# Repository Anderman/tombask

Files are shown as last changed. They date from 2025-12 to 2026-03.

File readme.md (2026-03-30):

Tosot (Gree) Hombask 200Liter

The signal is custom rs485
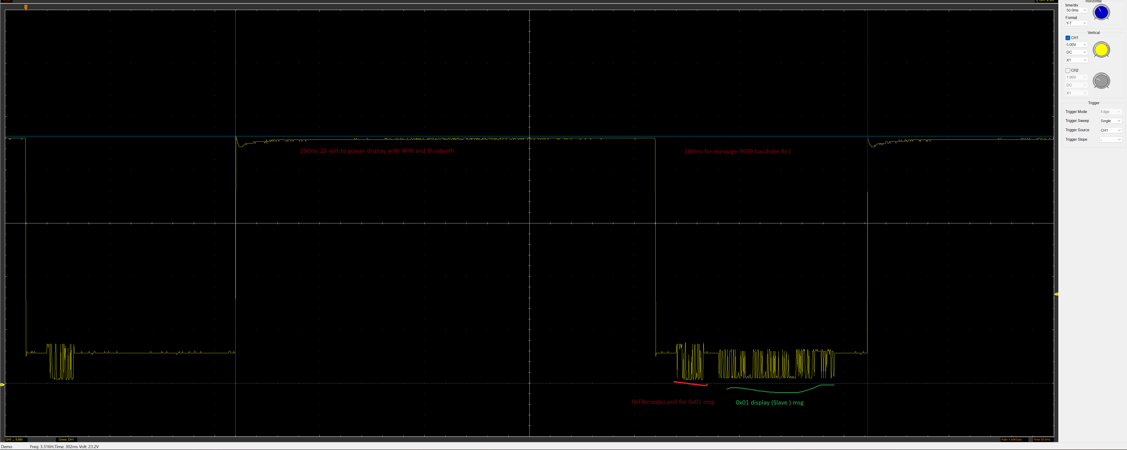
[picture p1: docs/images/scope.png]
RS485 scope capture


All message send
```
12-07 12:47:05 frame=7e 7e 00 f0 00 04 90 31 01 64 47 00 (poll slave 0x00)
12-07 12:47:06 frame=7e 7e 01 f0 00 04 90 31 01 74 87 00 (poll slave 0x01)
12-07 12:47:06 frame=7e 7e f0 01 02 2d 90 31 01 15 21 9a 40 4a 02 c0 02 05 01 c7 01 0c 02 0e 02 c4 00 24 01 17 b4 00 00 00 00 55 8e 5d a7 15 b0 8e 00 aa ff ff ff ff ff 73 4a 57 55 (response slave 0x01)
12-07 12:47:06 frame=7e 7e 02 f0 00 04 90 31 01 47 87 00 (poll slave 0x02)
12-07 12:47:06 frame=7e 7e f0 f0 04 2d 90 31 01 15 21 9a 40 4a 02 c0 02 05 01 c7 01 0c 02 0e 02 c4 00 24 01 17 b4 00 00 00 00 55 8e 5d a7 15 b0 8e 00 aa ff ff ff ff ff 73 73 f6 00 (broadcast master)
12-07 12:47:06 frame=7e 7e f0 f0 06 1c 90 31 01 15 2c c0 01 00 00 10 ff ff 00 00 af b4 04 4b 73 5f 5a 3a 4b 00 00 00 00 99 1f 00 (broadcast master)
12-07 12:47:07 frame=7e 7e f0 f0 02 3c 90 31 01 77 98 00 7d 00 00 00 00 76 00 74 75 00 00 10 01 01 90 00 00 00 00 f8 00 00 00 00 00 00 00 11 8c 0f 9f c6 1d 98 15 00 00 00 00 70 9a 00 00 00 00 02 00 00 00 00 02 00 00 5a f0 00 (broadcast master)
12-07 12:47:07 frame=7e 7e f0 f0 03 25 90 31 06 00 00 00 14 14 00 00 00 00 00 00 00 00 00 00 00 00 00 00 00 02 00 00 00 00 00 00 00 00 00 00 00 09 98 44 00 (broadcast master)
12-07 12:47:07 frame=7e 7e f0 f0 08 40 90 31 01 01 00 00 00 00 00 00 00 00 00 00 00 00 00 00 00 00 00 00 00 00 00 00 00 00 00 00 00 00 00 00 00 00 00 00 00 00 00 00 00 00 00 00 00 00 00 00 00 00 00 00 00 00 00 00 00 00 00 00 00 ae 60 00 (broadcast master)
```
Slave can send after a poll frame.
Slave is ready sending when the last padding byte is 0x55
To write byte 0x08 must be 0x02

Aansluiting Rs485 signal for wired controller on H1(pos) and H2(neg) of the XT3 connector
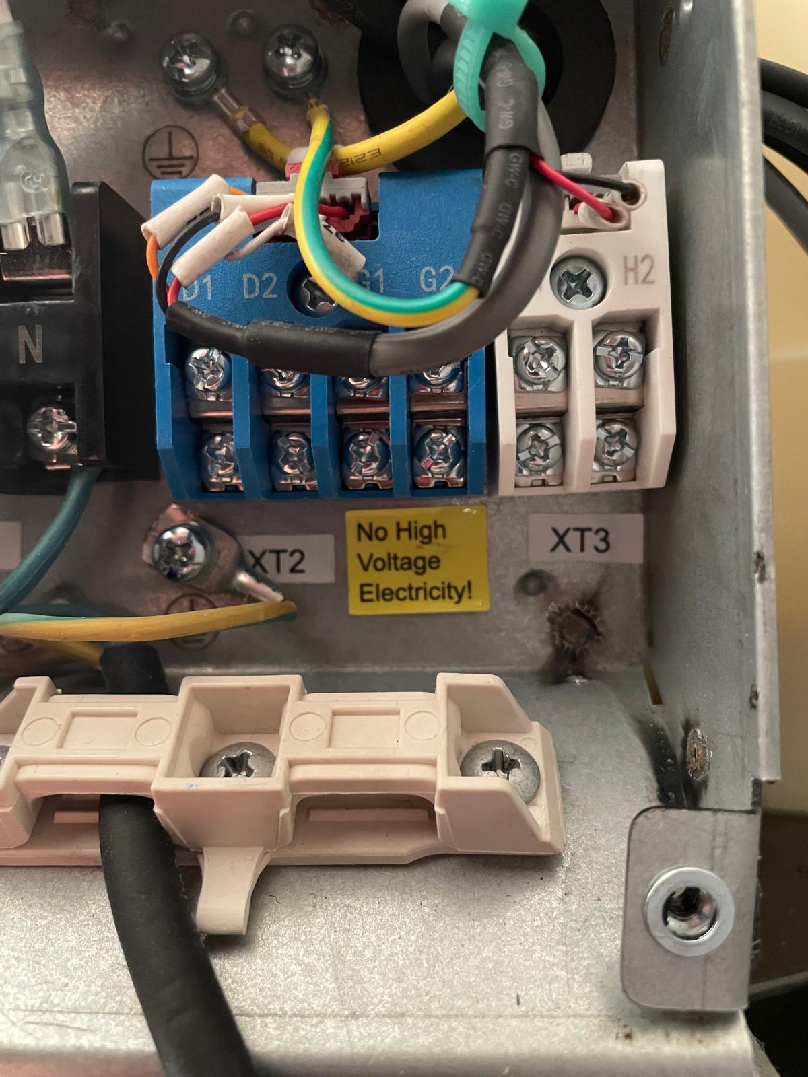
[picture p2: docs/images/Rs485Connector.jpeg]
RS485 connector


App 
## Control page

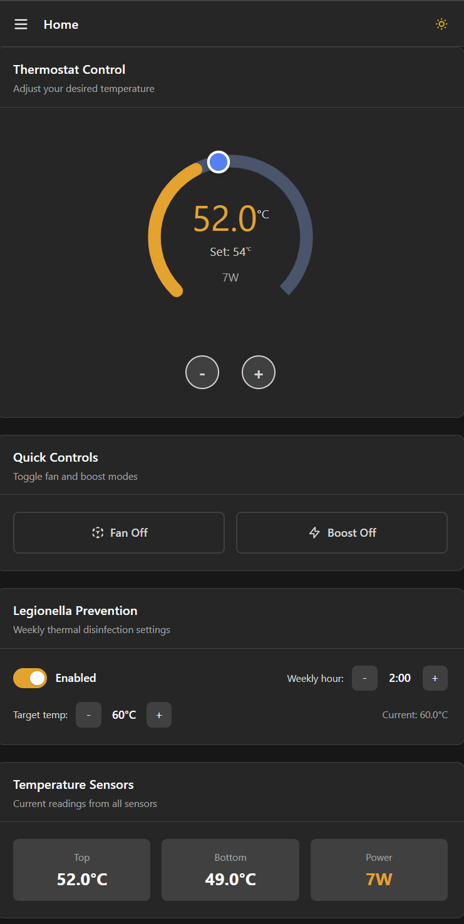
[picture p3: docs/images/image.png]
Control page


## temp history
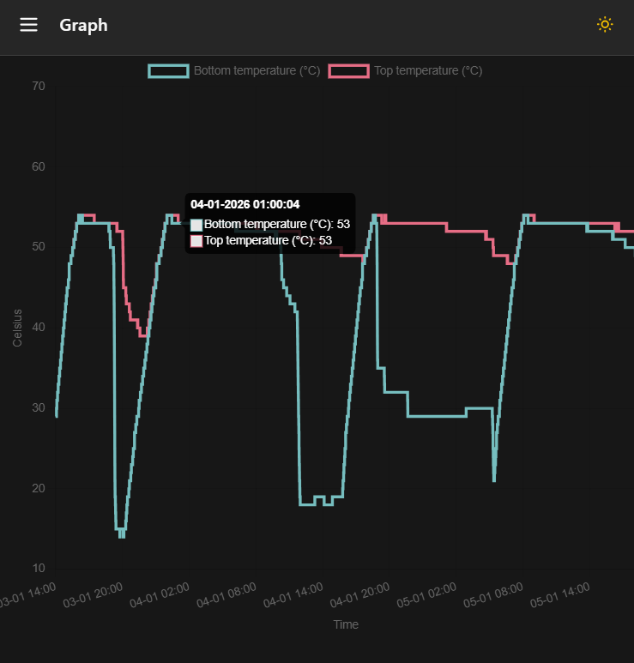
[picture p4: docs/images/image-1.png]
Temperature history


## mtqq settings
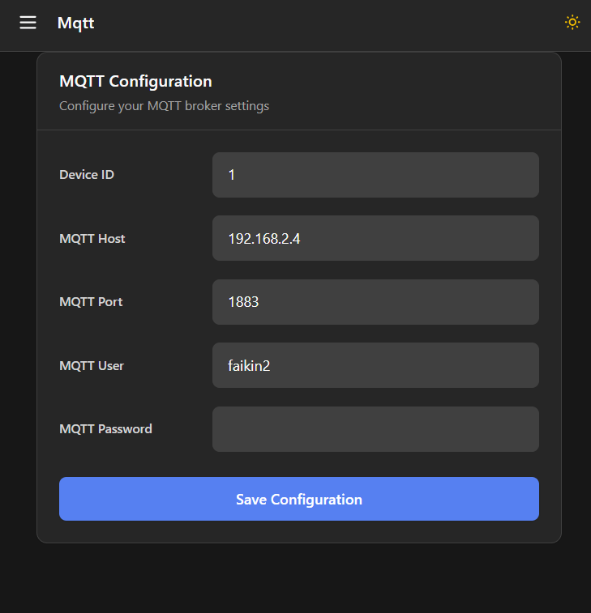
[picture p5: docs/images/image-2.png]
MQTT settings


## Logger (for debugging)
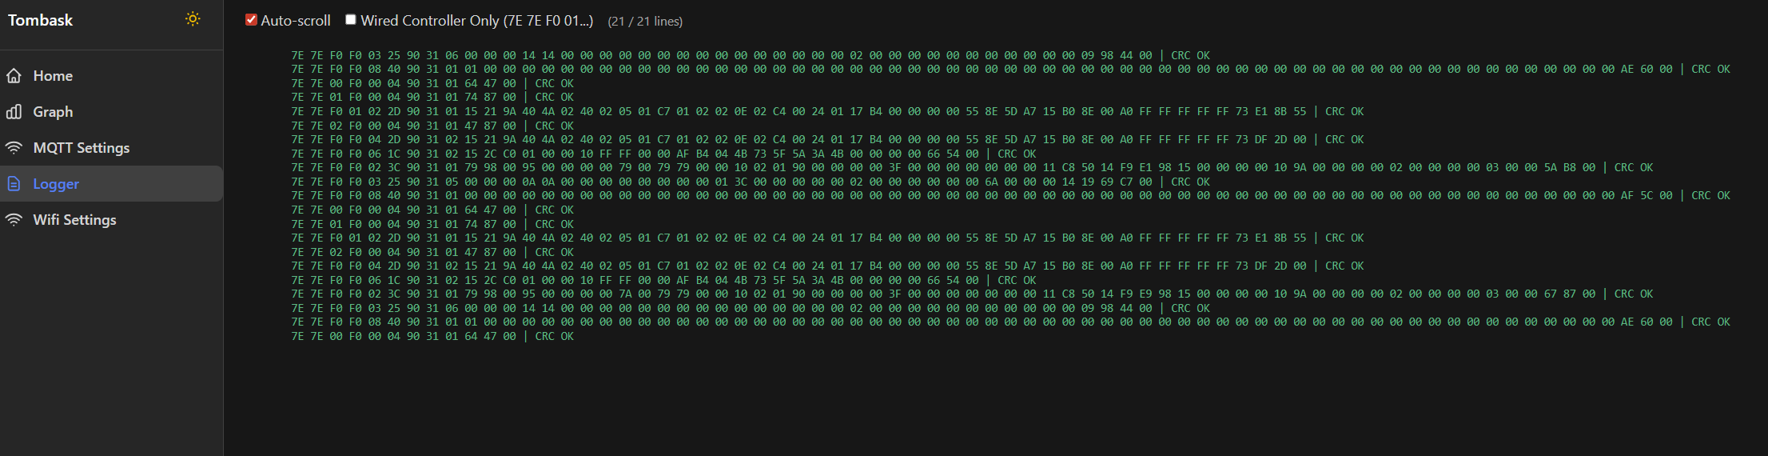
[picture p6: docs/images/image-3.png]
Logger


## wifi settings
This is the wifimanger plugin

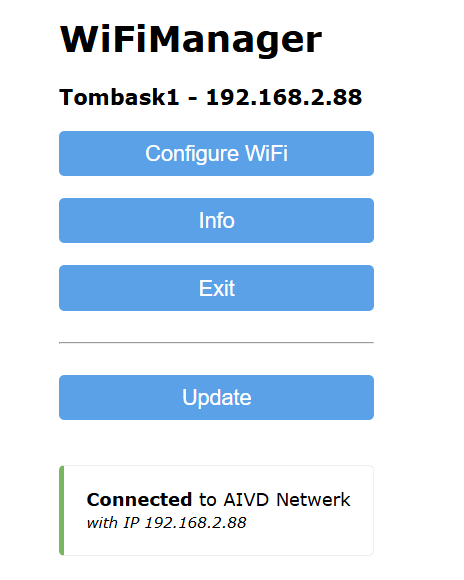
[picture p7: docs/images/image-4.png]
WiFi settings


PCB
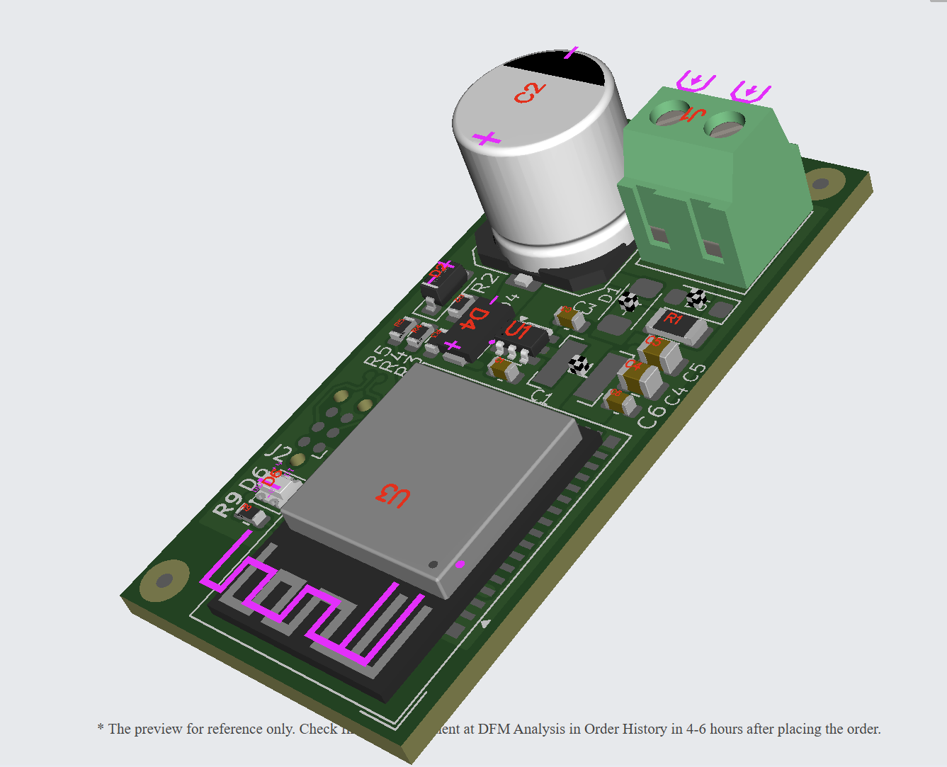
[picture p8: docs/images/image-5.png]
PCB


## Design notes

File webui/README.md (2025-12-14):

# Tombask Web UI

Minimal Svelte (Vite) web UI to edit device config on the ESP32.

## Dev

From `webui/`:
- `pnpm install`
- `pnpm run dev`

## Build

- `pnpm run build`

Output goes to `webui/dist/` with stable filenames:
- `dist/index.html`
- `dist/assets/app.js`
- `dist/assets/app.css`

## Expected device API

- `GET /api/config` -> JSON:
  ```json
  {
    "deviceId": "tombask-kitchen",
    "mqttHost": "192.168.2.4",
    "mqttPort": 1883,
    "wifiSsid": "MyWiFi",
    "wifiPassword": ""
  }
  ```
- `POST /api/config` (JSON) -> returns 200 OK (optionally JSON).

Recommended: device does not return the stored wifi password; only updates it when a non-empty value is posted.

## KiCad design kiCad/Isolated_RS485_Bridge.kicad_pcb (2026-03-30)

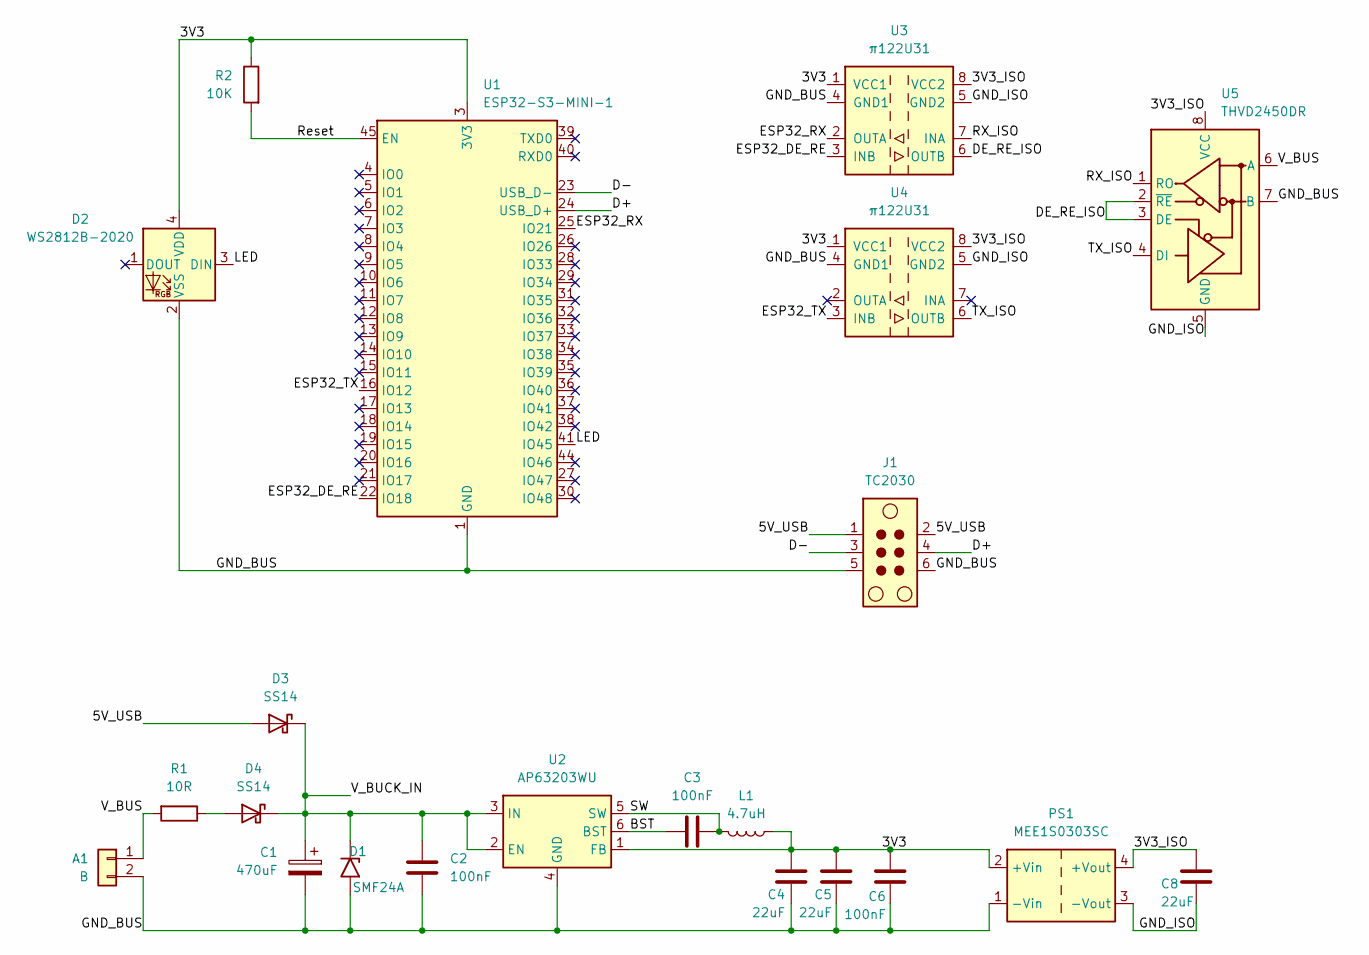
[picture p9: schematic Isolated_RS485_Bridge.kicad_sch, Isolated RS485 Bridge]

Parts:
A1: B; TerminalBlock_Phoenix_MKDS-1-2-3.81_1x02_P3.81mm_Horizontal; LCSC C5188452
C1: 470uF; CP_Elec_10x10; LCSC C3350
C2, C3, C6: 100nF; C_0603_1608Metric; LCSC C56476
C4, C5, C8: 22uF; C_0805_2012Metric; LCSC C45783
D1: SMF24A; D_SOD-123FL; LCSC C545276
D2: WS2812B-2020; LED_WS2812B-2020_2x2.2mm; LCSC C965555
D3, D4: SS14; D_SOD-323HE; LCSC C28646397
J1: TC2030; Tag-Connect_TC2030-IDC-NL_2x03_P1.27mm_Vertical
L1: 4.7uH; L_Bourns-SRN4018; LCSC C5159668
PS1: MEE1S0303SC; Converter_DCDC_Murata_MEE1SxxxxSC_THT; LCSC C7465185
R1: 10R; R_1206_3216Metric; LCSC C17903
R2: 10K; R_0603_1608Metric; LCSC C25804
U1: ESP32-S3-MINI-1; LCSC C3013941
U2: AP63203WU; TSOT-23-6; LCSC C780769
U3, U4: π122U31; SOIC-8_3.9x4.9mm_P1.27mm; LCSC C471590
U5: THVD2450DR; SOIC-8_3.9x4.9mm_P1.27mm; LCSC C2672621

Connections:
/3V3: C4.1, C5.1, C6.2, D2.4 (VDD), L1.1, PS1.2 (+Vin), R2.1, U1.3 (3V3), U2.1 (FB), U3.1 (VCC1), U4.1 (VCC1)
/3V3_ISO: C8.1, PS1.4 (+Vout), U3.8 (VCC2), U4.8 (VCC2), U5.8 (VCC)
/5V_USB: D3.2 (A), J1.1, J1.2
/BST: C3.2, U2.6 (BST)
/D+: J1.4, U1.24 (USB_D+)
/D-: J1.3, U1.23 (USB_D-)
/DE_RE_ISO: U3.6 (OUTB), U5.2 (~RE), U5.3 (DE)
/ESP32_DE_RE: U1.22 (IO18), U3.3 (INB)
/ESP32_RX: U1.25 (IO21), U3.2 (OUTA)
/ESP32_TX: U1.16 (IO12), U4.3 (INB)
/GND_BUS: A1.2, C1.2, C2.2, C4.2, C5.2, C6.1, D1.2 (A2), D2.2 (VSS), J1.5, J1.6, PS1.1 (-Vin), U1.1 (GND), U1.2 (GND), U1.42 (GND), U1.43 (GND), U1.46 (GND), U1.47 (GND), U1.48 (GND), U1.49 (GND), U1.50 (GND), U1.51 (GND), U1.52 (GND), U1.53 (GND), U1.54 (GND), U1.55 (GND), U1.56 (GND), U1.57 (GND), U1.58 (GND), U1.59 (GND), U1.60 (GND), U1.61 (GND), U1.62 (GND), U1.63 (GND), U1.64 (GND), U1.65 (GND), U2.4 (GND), U3.4 (GND1), U4.4 (GND1), U5.7 (B)
/GND_ISO: C8.2, PS1.3 (-Vout), U3.5 (GND2), U4.5 (GND2), U5.5 (GND)
/LED: D2.3 (DIN), U1.41 (IO45)
/RX_ISO: U3.7 (INA), U5.1 (RO)
/Reset: R2.2, U1.45 (EN)
/SW: C3.1, L1.2, U2.5 (SW)
/TX_ISO: U4.6 (OUTB), U5.4 (DI)
/V_BUCK_IN: C1.1, C2.1, D1.1 (A1), D3.1 (K), D4.1 (K), U2.2 (EN), U2.3 (IN)
/V_BUS: A1.1, R1.2, U5.6 (A)
unnamed: D4.2 (A), R1.1

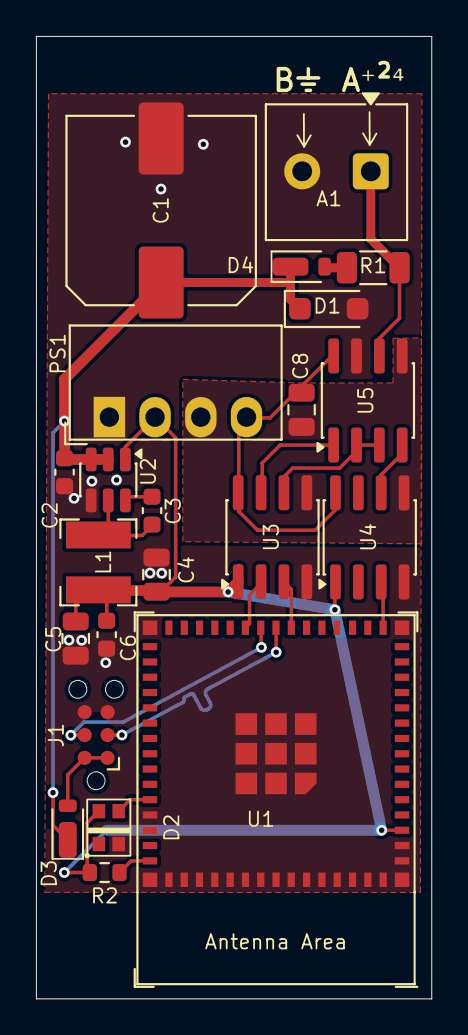
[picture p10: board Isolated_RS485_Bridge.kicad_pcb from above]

Board: 2 copper layers, 22.0 x 53.5 mm, 22 parts (0 on the bottom side), 20 nets.

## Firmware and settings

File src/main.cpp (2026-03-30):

#include <Arduino.h>
#include <WiFi.h>
#include <PubSubClient.h>
#include <ArduinoOTA.h>
#include <cstdio>
#include "secrets.h"
#include "mqtt/setup.h"
#include "mqtt/mqttLoop.h"
#include "Ota.h"
#include "ota/auto_update.h"
#include "wifiSetup.h"
#include "rs485/rs485.h"
#include "storage/storage.h"
#include "storage/sensor_log.h"
#include "webui/webui.h"
#include "rs485/settings.h"
#include "status_led.h"

// ==== GLOBALS ====
WiFiClient espClient;
PubSubClient mqttClient(espClient);
unsigned long lastPublish = 0;

void setup()
{
  Serial.begin(115200);
  delay(2000);
  Serial.println();
  Serial.println("[tombask] boot");

  statusLedSetup();
  // Boot indication (dim blue)
  statusLedSetRgb(0, 0, 16);

  loadConfig();
  listNvsKeys();
  loadAllSensorLogs();
  Serial.print("[tombask] deviceId=");
  Serial.println(deviceId);
  setupWifi();
  Serial.print("setupWifi done, IP=");
  Serial.print(WiFi.localIP());
  Serial.println();
  setupOTA();
  setupWebUi();
  setupAutoUpdate();
  setupWifiConfigPage();
  Serial.print("[tombask] webui started: http://");
  Serial.print(WiFi.localIP());
  Serial.println("/");
  setupMqtt();
  setupRs485();
  Serial.println("[tombask] setup done");

  // Ready indication (dim green)
  statusLedSetRgb(0, 16, 0);
}

void loop()
{
  static unsigned long lastLogSave = 0;
  ArduinoOTA.handle();
  autoUpdateLoop();
  webUiLoop();
  wifiManagerLoop();
  mqttLoop();
  rs485Loop();
  if (millis() - lastLogSave > 1UL * 60 * 1000) { // elke 1 min
    saveAllSensorLogs();
    lastLogSave = millis();
  }
}

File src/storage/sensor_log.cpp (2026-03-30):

#include <FS.h>
#include <ArduinoJson.h>
#include <Preferences.h>
#include "sensor_log.h"
#include <time.h>
#include <set>

// Forward declarations for logs in each frame file
SensorLog topTempLog("TTop");
SensorLog bottomTempLog("TBottom");
static SensorLog *const allLogs[] = {&topTempLog, &bottomTempLog};

SensorLog::SensorLog(const char *name, size_t maxEntries)
    : _maxEntries(maxEntries), name(name) {}

void SensorLog::log(int16_t value)
{
    u_int32_t timestamp = time(nullptr); // epoch seconds
    while (entries.size() >= _maxEntries)
    {
        entries.erase(entries.begin()); // ringbuffer: verwijder oudste
    }
    entries.push_back({timestamp, value});
}

void SensorLog::logIfChanged(int16_t logValue)
{
    const size_t bufferSize = 5;
    _lastValues.push_back(logValue);
    if (_lastValues.size() > bufferSize)
    {
        _lastValues.erase(_lastValues.begin());
    }

    if (_lastValues.size() == 1)
    {
        return;
    }
    const int16_t prevLogValue = _lastValues[_lastValues.size() - 2];
    size_t n = entries.size();
    if (n == 0)
    {
        log(prevLogValue);
        return;
    }

    int16_t last = entries.back().value;
    if (prevLogValue == last)
    {
        return;
    }

    // Flip-detectie: check of buffer alleen uit 2 waarden bestaat en die afwisselt
    std::set<int16_t> uniqueVals(_lastValues.begin(), _lastValues.end());

    bool mustLog = false;
    if (n >= 2 && uniqueVals.size() != 1)
    {
        // Flip-detectie: als we flippen tussen 2 waarden, log niet
        int16_t prev = entries[n - 2].value;
        mustLog = (logValue != last && logValue != prev);
        if (prevLogValue == prev && !mustLog)
        {
            return;
        }
    }
    if (entries.empty() || last != prevLogValue || mustLog)
    {
        log(prevLogValue);
        return;
    }
}

// Helper: log opslaan in NVS (Preferences) per log
void saveAllSensorLogs()
{
    Preferences prefs;
    for (auto *log : allLogs)
    {
        String nvsKey = log->name;
        if (!prefs.begin(nvsKey.c_str(), false))
        {
            Serial.print("[sensor_log] ERROR: NVS open failed for namespace: ");
            Serial.println(nvsKey);
            continue;
        }
        size_t n = log->entries.size();
        {
            prefs.putBytes("data", log->entries.data(), n * sizeof(SensorLogEntry));
            prefs.putUInt("count", n);
        }
        prefs.end();
    }
}

// Helper: log teruglezen uit NVS (Preferences) per log
void loadAllSensorLogs()
{
    Preferences prefs;
    for (auto *log : allLogs)
    {
        String nvsKey = log->name;
        if (!prefs.begin(nvsKey.c_str(), true))
        {
            Serial.print("[sensor_log] ERROR: NVS open failed for namespace: ");
            Serial.println(nvsKey);
            continue;
        }
        size_t n = prefs.getUInt("count", 0);
        log->entries.clear();
        if (n > 0)
        {
            log->entries.resize(n);
            prefs.getBytes("data", log->entries.data(), n * sizeof(SensorLogEntry));
        }
        Serial.printf("[sensor_log] Loaded %u entries for log ", n);
        Serial.println(nvsKey);
        prefs.end();
    }
}

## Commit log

2025-12-31 add kicad
    [Connectors.kicad_sch, ESP32.kicad_sch, Isolated_RS485_Bridge.kicad_sch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]
2026-01-05 Add Pcb
    [Connectors.kicad_sch, ESP32.kicad_sch, Isolated_RS485_Bridge.kicad_pcb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]
2026-03-30 first working version with last kicad design
    [ESP32.kicad_sch, Isolated_RS485_Bridge.kicad_pcb, Isolated_RS485_Bridge.kicad_sch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]
